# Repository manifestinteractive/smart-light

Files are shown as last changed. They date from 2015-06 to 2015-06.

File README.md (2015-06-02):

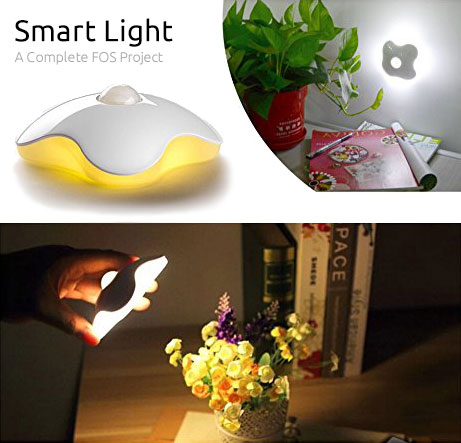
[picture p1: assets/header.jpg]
smart light


# Smart Light v1.0.0

#### Smart Light ( Arduino Sketch, Fritzing Schematic &amp; Mobile App )

Build your own Smart Light with this Complete FOS Project.  The completed project will allow you to use a free mobile application to control how &amp; when you want your Smart Light to work.  We are also releasing our Smart Light Mobile App as part of this project.

The main goal of this project is to show how anyone can build their own Custom Product from Start to Finish.  You now have with Custom Software, and even control that Product with a powerful Mobile Application.

Parts List
---

#### You will need to purchase the following hardware:

* `ARD` [Arduino Pro Mini 328 - 5V/16 MHz](https://www.adafruit.com/products/2378?utm_medium=referral&utm_source=manifestinteractive)
* `PIR` [PIR (motion) sensor](https://www.adafruit.com/products/189?utm_medium=referral&utm_source=manifestinteractive)
* `NEO` [NeoPixel Ring - 12 x WS2812 5050 RGB LED with Integrated Drivers](https://www.adafruit.com/products/1643?utm_medium=referral&utm_source=manifestinteractive)
* `LUX` [Adafruit TSL2561 Digital Luminosity/Lux/Light Sensor Breakout](https://www.adafruit.com/products/439?utm_medium=referral&utm_source=manifestinteractive)
* `BLU` [Bluefruit LE - Bluetooth Low Energy (BLE 4.0) - nRF8001 Breakout - v1.0](https://www.adafruit.com/products/1697?utm_medium=referral&utm_source=manifestinteractive)
* `SDC` [Mini DC/DC Step-Down (Buck) Converter - 5V @ 1A output - TSR12450](https://www.adafruit.com/products/1065?utm_medium=referral&utm_source=manifestinteractive)

#### Optional Parts:

* [FTDI Serial TTL-232 USB Cable](https://www.adafruit.com/products/70?utm_medium=referral&utm_source=manifestinteractive) ( I use this to program the Arduino boards )
* [4 x AA Battery Holder with On/Off Switch](https://www.adafruit.com/products/830?utm_medium=referral&utm_source=manifestinteractive) ( needed if your enclosure does not have battery space )
* [Adafruit Perma-Proto Quarter-sized Breadboard PCB](https://www.adafruit.com/products/1608?utm_medium=referral&utm_source=manifestinteractive) ( might make wiring a little easier )
* [6-conductor 0.1" socket-socket cable - 6" long](https://www.adafruit.com/products/206?utm_medium=referral&utm_source=manifestinteractive) ( I cut these in half and use them to extend FTDI access to program Arduino boards )

#### Optional Enclosure:

I found it was actually cheaper to just get an existing Motion Light and replace it's components with the list above.  This is the enclosure I went with for this project:

* [Hallomall™ Clover Style Night Lights](http://www.amazon.com/gp/product/B00MLW99MK?utm_medium=referral&utm_source=manifestinteractive)

Wiring Instructions
---

| Part | Pin | > | Part | Pin  | Cable  |
|---|---|---|---|---|---|
| __PIR__  | Red | > | ARD  | VCC  | Red |
| PIR | Yellow | > | ARD  | 3 | Yellow |
| PIR | Black  | > | ARD  | GND  | Black  |
| __NEO__  | PWR | > | ARD  | VCC  | Red |
| NEO | IN | > | ARD  | 6 | Blue |
| NEO | GND | > | ARD  | GND  | Black  |
| __LUX__  | VIN | > | ARD  | VCC  | Red |
| LUX | GND | > | ARD  | GND  | Black  |
| LUX | SDA | > | ARD  | A4 | Yellow |
| LUX | SCL | > | ARD  | A5 | Blue |
| __BLU__  | SCK | > | ARD  | 13 | Blue |
| BLU | MISO | > | ARD  | 12 | Yellow |
| BLU | MOSI | > | ARD  | 11 | Orange |
| BLU | REQ | > | ARD  | 10 | Grey |
| BLU | RDY | > | ARD  | 2 | White  |
| BLU | RST | > | ARD  | 9 | Orange |
| BLU | GND | > | ARD  | GND  | Black  |
| BLU | VIN | > | ARD  | VCC  | Red |

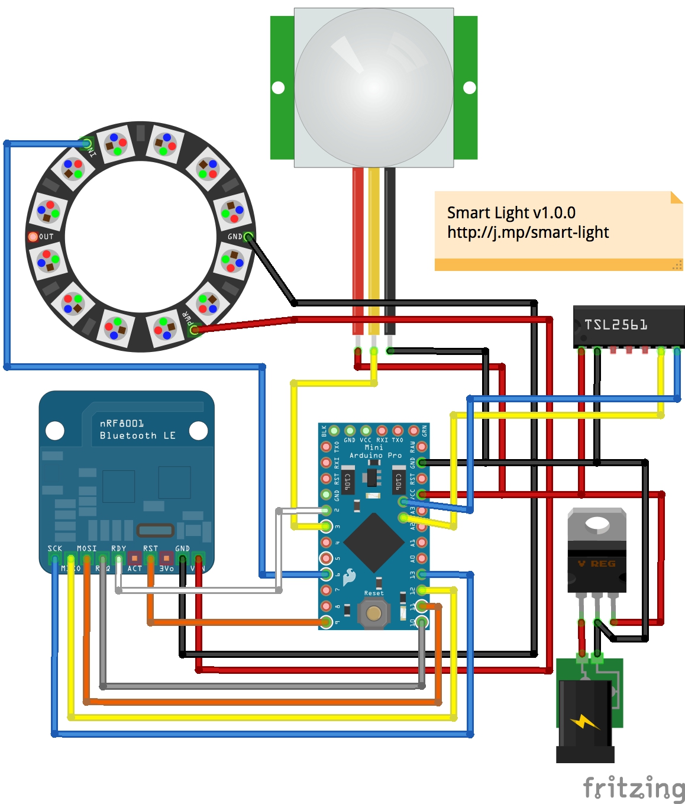
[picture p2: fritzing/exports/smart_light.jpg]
wiring


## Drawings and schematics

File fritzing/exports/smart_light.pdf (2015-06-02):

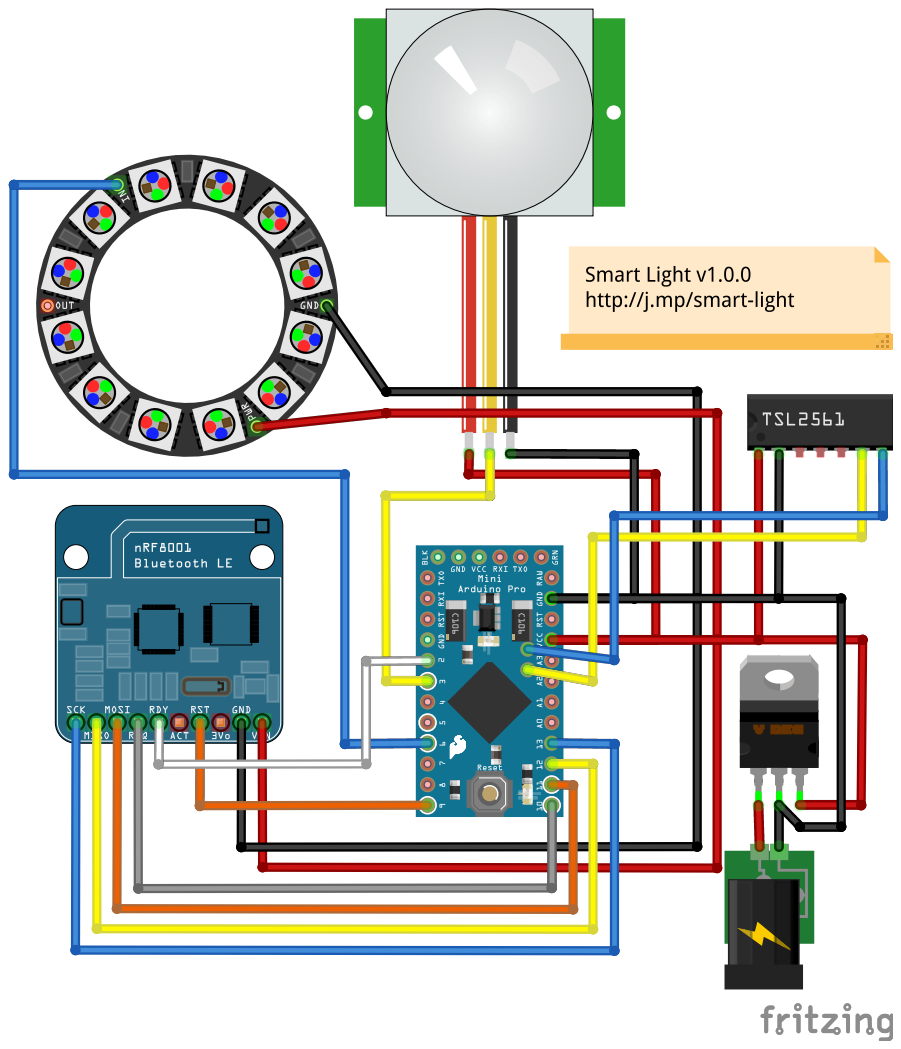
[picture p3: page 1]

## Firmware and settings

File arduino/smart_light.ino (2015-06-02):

#include <Wire.h>
#include <Adafruit_Sensor.h>
#include <Adafruit_TSL2561_U.h>
#include <Adafruit_NeoPixel.h>
#include <RunningAverage.h>
#include <SPI.h>
#include <Adafruit_BLE_UART.h>

/* --- General Settings --- */

boolean lightIsOn = false;
boolean roomIsDark = false;
boolean inMotion = false;

/* --- Motion Sensor Settings --- */

boolean motionStart;
boolean motionLock = true;
int calibrationTime = 15;
unsigned long int pause = 5000;
unsigned long int startTime;
unsigned long int endTime;
unsigned long int totalTime;
unsigned long int motionStoppedTime;

/* --- NeoPixel Settings --- */

int lightBrightness = 50;
Adafruit_NeoPixel pixels = Adafruit_NeoPixel(12, 6, NEO_GRB + NEO_KHZ800);

/* --- Light Sensor Settings --- */

Adafruit_TSL2561_Unified tsl = Adafruit_TSL2561_Unified(TSL2561_ADDR_FLOAT, 12345);
RunningAverage lightReadingAverage(10);

/* --- Bluetooth Settings --- */

Adafruit_BLE_UART BTLEserial = Adafruit_BLE_UART(10, 2, 9);
aci_evt_opcode_t laststatus = ACI_EVT_DISCONNECTED;

/* --- Main Arduino Functions --- */

void setup(){
  Serial.begin(9600);
  setupMotion();
  setupNeoPixel();
  setupLightSensor();
  //setupBluetooth();
}

void loop(){
  checkForMotion();
  checkForLight();
  //checkForBluetooth();
  delay(100);
}

/* --- Motion Sensor Functions --- */

void setupMotion(){
  pinMode(3, INPUT);
  digitalWrite(3, LOW);

  Serial.println("Calibrating Motion Sensor. Do not move for 15 Seconds.");
  for(int i = 0; i < calibrationTime; i++){
    delay(1000);
    Serial.print(".");
  }
  Serial.println(" ");
  Serial.println("Calibration Complete.");
}

void checkForMotion(){
  if(digitalRead(3) == HIGH){
    if(motionLock){
      motionStarted();
    }
    motionStart = true;
  }

  if(digitalRead(3) == LOW){
    if(motionStart){
      motionStoppedTime = millis();
      motionStart = false;
    }
    if( !motionLock && millis() - motionStoppedTime > pause){
      motionEnded();
    }
  }
}

void motionStarted(){
  Serial.println("Motion Started");
  motionLock = false;
  inMotion = true;
  startTime = millis()/1000;
  endTime = 0;
  totalTime = 0;

  if(roomIsDark == true)
  {
    turnLightOn();
  }
}

void motionEnded(){
  Serial.println("Motion Ended");
  motionLock = true;	
  inMotion = false;
  endTime = (millis() - pause)/1000;
  totalTime = (endTime - startTime);

  turnLightOff();
}

bool getInMotion()
{
  return inMotion;
}

/* --- NeoPixel Functions --- */

void setupNeoPixel(){
  pixels.begin();
  pixels.setBrightness(lightBrightness);
  pixels.show();
}

void turnLightOn(){
  if( !lightIsOn)
  {
    Serial.println("Turning Light On");
    lightIsOn = true;
    for(int i=0;i<12;i++){
      lightBrightness += 10;
      pixels.setPixelColor(i, pixels.Color(150,150,150));
      pixels.setBrightness(lightBrightness);
      pixels.show();
      delay(25);
    }
  } 
}

void turnLightOff(){
  if(lightIsOn)
  {
    Serial.println("Turning Light Off");
    lightIsOn = false;
    for(int i=0;i<12;i++){
      lightBrightness -= 10;
      pixels.setPixelColor(i, pixels.Color(0,0,0));
      pixels.setBrightness(lightBrightness);
      pixels.show();
      delay(25);
    }
  }
}

/* --- Light Sensor Functions --- */

void setupLightSensor(){
  tsl.begin();
  tsl.enableAutoRange(true);
  tsl.setIntegrationTime(TSL2561_INTEGRATIONTIME_13MS);
}

void checkForLight(){
  sensors_event_t event;
  tsl.getEvent(&event);
 
  if (event.light >= 0)
  {
    lightReadingAverage.addValue(event.light);
  }
  
  if(lightReadingAverage.getAverage() <= 10 && !roomIsDark)
  {
    Serial.println("Room is now dark");
    roomIsDark = true;
    
    if(getInMotion())
    {
      turnLightOn();
    }
  }
  else if(lightReadingAverage.getAverage() > 10 && roomIsDark)
  {
    Serial.println("Room is no longer dark");
    roomIsDark = false;
  }
}

/* --- Bluetooth Functions --- */

void setupBluetooth(){
  BTLEserial.setDeviceName("MyLight");
  BTLEserial.begin();
}

void checkForBluetooth(){
// Tell the nRF8001 to do whatever it should be working on.
  BTLEserial.pollACI();
  
  // Ask what is our current status
  aci_evt_opcode_t status = BTLEserial.getState();
  // If the status changed....
  if (status != laststatus) {
    // print it out!
    if (status == ACI_EVT_DEVICE_STARTED) {
        Serial.println(F("* Waiting for Bluetooth Device Connection"));
    }
    if (status == ACI_EVT_CONNECTED) {
        Serial.println(F("* Bluetooth Device Connected!"));
    }
    if (status == ACI_EVT_DISCONNECTED) {
        Serial.println(F("* Disconnected or Connection timed out"));
    }
    // OK set the last status change to this one
    laststatus = status;
  }
  
  if (status == ACI_EVT_CONNECTED) {
    // Lets see if there's any data for us!
    if (BTLEserial.available()) {
      Serial.print("* "); Serial.print(BTLEserial.available()); Serial.println(F(" bytes available from BTLE"));
    }
    // OK while we still have something to read, get a character and print it out
    while (BTLEserial.available()) {
      char c = BTLEserial.read();
      Serial.print(c);
    }
    
    // Next up, see if we have any data to get from the Serial console
 
    if (Serial.available()) {
      // Read a line from Serial
      Serial.setTimeout(100); // 100 millisecond timeout
      String s = Serial.readString();
 
      // We need to convert the line to bytes, no more than 20 at this time
      uint8_t sendbuffer[20];
      s.getBytes(sendbuffer, 20);
      char sendbuffersize = min(20, s.length());
      
      Serial.print(F("\n* Sending -> \"")); Serial.print((char *)sendbuffer); Serial.println("\"");
      
      // write the data
      BTLEserial.write(sendbuffer, sendbuffersize);
    }
  }

}

void receivedMessage(String message)
{
}

void sendMessage(String message)
{
}
